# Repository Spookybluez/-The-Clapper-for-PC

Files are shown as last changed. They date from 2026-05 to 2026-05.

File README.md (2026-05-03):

# ESP32 PC Wake/Sleep Voice Bridge

An ESP32 prototype that listens through an I2S microphone and sends PC wake/sleep commands over the local network.

The current trigger is a calibrated clap detector. The network-control layer is ready for a future phrase recognizer such as "computer wake up" and "computer go to sleep."

## What It Does

- Reads a 6-pin I2S microphone from an ESP32.
- Uses a clap-style trigger to toggle desired PC state.
- Sends Wake-on-LAN packets to wake the PC.
- Sends an HTTP request to a small Windows listener to put the PC to sleep.
- Includes a dongle-style 3D-printable enclosure.

## Project Layout

| Path | Purpose |
| --- | --- |
| `PcWakeSleepVoiceBridge/` | Main ESP32 WiFi + Wake-on-LAN + sleep-listener firmware |
| `PcWakeSleepVoiceBridge/pc_power_listener.py` | Windows HTTP listener for dry-run and real sleep/shutdown actions |
| `PcWakeSleepVoiceBridge/arduino_secrets.example.h` | Template for local WiFi credentials |
| `ClapToggleWakeSensor/` | Earlier standalone I2S clap-toggle sketch |
| `UsbSerialWakeSleepBridge/` | Experimental USB-serial bridge variant |
| `enclosure/` | STL files and generator for the dongle-style case |

## Hardware

- ESP32 DevKit-style board
- 6-pin I2S microphone, such as INMP441-style modules
- USB power supply or USB cable
- PC with Wake-on-LAN-capable Ethernet adapter

I2S microphone wiring:

| Mic Pin | ESP32 Pin |
| --- | --- |
| `VDD` | `3V3` |
| `GND` | `GND` |
| `SCK` | `GPIO26` |
| `WS` | `GPIO25` |
| `SD` | `GPIO33` |
| `L/R` | `GND` |

## Main Firmware Setup

Copy the secrets template:

```powershell
copy .\PcWakeSleepVoiceBridge\arduino_secrets.example.h .\PcWakeSleepVoiceBridge\arduino_secrets.h
```

Edit `arduino_secrets.h` with your WiFi network:

```cpp
const char* WIFI_SSID = "YOUR_WIFI_NAME";
const char* WIFI_PASSWORD = "YOUR_WIFI_PASSWORD";
```

The PC target is configured in `PcWakeSleepVoiceBridge.ino`:

```cpp
const byte PC_MAC[6] = {0x34, 0x5A, 0x60, 0x10, 0x9F, 0x36};
const char* PC_SLEEP_URL = "http://192.168.1.191:8787/sleep";
```

Upload with Arduino IDE or Arduino CLI using an ESP32 Dev Module target.

## Windows Listener

Start in dry-run mode first:

```powershell
python .\PcWakeSleepVoiceBridge\pc_power_listener.py --dry-run
```

Dry-run endpoints report success without sleeping the PC.

When ready for the real sleep action:

```powershell
python .\PcWakeSleepVoiceBridge\pc_power_listener.py
```

Available endpoints:

- `GET /health`
- `POST /sleep`
- `POST /shutdown`

## Serial Test Commands

Open Serial Monitor at `115200` baud and send:

```text
WAKE_TEST
SLEEP_TEST
WAKE_IN_30
WAKE_SPAM_120
```

- `WAKE_TEST` sends one Wake-on-LAN packet.
- `SLEEP_TEST` calls the PC listener `/sleep` endpoint.
- `WAKE_IN_30` sends Wake-on-LAN after 30 seconds.
- `WAKE_SPAM_120` sends Wake-on-LAN repeatedly for 2 minutes.

## Wake-on-LAN Requirements

The PC must be configured to wake from the network adapter:

- BIOS/UEFI PCIe wake enabled
- Windows network adapter Power Management allows wake
- `Wake on Magic Packet` enabled in the adapter's advanced settings
- Ethernet connected to the active adapter

## Enclosure

Generated STL files:

- `enclosure/esp32_dongle_case_bottom.stl`
- `enclosure/esp32_dongle_case_lid.stl`

The case is a dongle-style shell with USB exiting the short end and mic grille slots on top.

## Safety Notes

- The firmware stores WiFi credentials in `arduino_secrets.h`, which is ignored by git.
- Use `--dry-run` before allowing the listener to sleep or shut down the PC.
- Wake-on-LAN can wake a sleeping/off PC only when BIOS, Windows, and the network adapter support it.

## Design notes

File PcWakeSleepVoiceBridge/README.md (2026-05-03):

# ESP32 PC Wake/Sleep Bridge

This version does not touch the motherboard `PWR_SW` header. The ESP32 sends signals to the PC over the network.

## What Works When

| PC state | Method | Requirement |
| --- | --- | --- |
| PC off/sleeping | Wake-on-LAN magic packet | Wake-on-LAN enabled in BIOS/UEFI and Windows/NIC settings |
| PC awake | HTTP request to listener | `pc_power_listener.py` running on the PC |

If the PC is fully off and Wake-on-LAN is disabled, the ESP32 cannot turn it on over USB/serial because the operating system is not running.

## ESP32 Setup

Create `arduino_secrets.h` from the example:

```powershell
copy .\arduino_secrets.example.h .\arduino_secrets.h
```

Then edit `arduino_secrets.h`:

```cpp
const char* WIFI_SSID = "YOUR_WIFI_NAME";
const char* WIFI_PASSWORD = "YOUR_WIFI_PASSWORD";
const char* PC_POWER_TOKEN = "MATCH_THE_TOKEN_IN_pc_listener_token.txt";
```

The PC target is currently configured in `PcWakeSleepVoiceBridge.ino`:

```cpp
const byte PC_MAC[6] = {0x34, 0x5A, 0x60, 0x10, 0x9F, 0x36};
const char* PC_SLEEP_URL = "http://192.168.1.191:8787/sleep";
```

The I2S mic wiring stays:

| Mic | ESP32 |
| --- | --- |
| VDD | 3V3 |
| GND | GND |
| SCK | GPIO26 |
| WS | GPIO25 |
| SD | GPIO33 |
| L/R | GND |

## Windows Listener

Create a local listener token file on the PC:

```powershell
[guid]::NewGuid().ToString('N') | Set-Content .\pc_listener_token.txt
```

Use the same token value for `PC_POWER_TOKEN` in `arduino_secrets.h`. The ESP32 sends it in the `X-Clapper-Token` header, and the listener rejects power commands without it.

Dry-run test:

```powershell
python .\pc_power_listener.py --dry-run --token (Get-Content .\pc_listener_token.txt)
```

Real sleep mode:

```powershell
python .\pc_power_listener.py --token (Get-Content .\pc_listener_token.txt)
```

Dry-run is strongly recommended first. Without `--dry-run`, `POST /sleep` will put the PC to sleep.

## ESP32 Serial Test Commands

Open Serial Monitor at `115200` baud and send one of:

```text
STATUS
THRESHOLD_1800
VERBOSE_ON
VERBOSE_OFF
CALIBRATE
WAKE_TEST
SLEEP_TEST
WAKE_IN_30
WAKE_SPAM_120
```

- `STATUS` prints Wi-Fi, mic, threshold, and action counters.
- `THRESHOLD_1800` changes the clap threshold. Replace `1800` with the target value.
- `VERBOSE_ON` / `VERBOSE_OFF` toggles periodic audio telemetry.
- `CALIBRATE` reruns the room-noise calibration.
- `WAKE_TEST` sends one Wake-on-LAN packet.
- `SLEEP_TEST` calls the PC listener `/sleep` endpoint.
- `WAKE_IN_30` sends Wake-on-LAN after 30 seconds.
- `WAKE_SPAM_120` sends Wake-on-LAN repeatedly for 2 minutes, useful for sleep/wake testing.

Set `VERBOSE_AUDIO_LOGS = true` in the sketch if you need raw mic tuning output again.

## ESP32 LAN Health Check

When the ESP32 is online, it exposes a read-only status endpoint:

```text
http://192.168.1.184:8080/health
```

The response includes Wi-Fi RSSI, uptime, mic readings, threshold, desired state, wake packet count, sleep request count, and the last sleep HTTP status. This endpoint does not trigger wake, sleep, or shutdown.

Remote tuning endpoints are available on the same port. These require the shared `X-Clapper-Token` header:

```powershell
$token = (Get-Content -Raw .\pc_listener_token.txt).Trim()
$headers = @{ "X-Clapper-Token" = $token }

Invoke-WebRequest -Method POST -UseBasicParsing -Headers $headers `
  -Uri "http://192.168.1.184:8080/config?threshold=1800&verbose=false"

Invoke-WebRequest -Method POST -UseBasicParsing -Headers $headers `
  -Uri "http://192.168.1.184:8080/calibrate"

Invoke-WebRequest -Method POST -UseBasicParsing -Headers $headers `
  -Uri "http://192.168.1.184:8080/wake_test"

Invoke-WebRequest -Method POST -UseBasicParsing -Headers $headers `
  -Uri "http://192.168.1.184:8080/reset_counters"
```

- `/config` can set `threshold` from `1` to `20000` and `verbose` to `true` or `false`.
- `/calibrate` reruns the mic room-noise calibration.
- `/wake_test` sends a Wake-on-LAN packet and increments `wakePacketsSent`.
- `/reset_counters` clears wake/sleep counters and the last sleep HTTP status.

There is intentionally no remote ESP endpoint for sleep. Sleep still only happens from the clap flow or the serial `SLEEP_TEST` command, which prevents accidental PC sleep while tuning over LAN.

## Voice Recognition

The included ESP32 sketch still uses the clap detector as a placeholder trigger. Exact phrase recognition like "computer wake up" and "computer go to sleep" should be added with an ESP32-S3/ESP-SR flow or a dedicated offline voice-recognition module. The network wake/sleep actions in this folder can remain the output layer.

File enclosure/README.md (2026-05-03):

# ESP32 Dongle-Style Enclosure

Generated STL files:

- `esp32_dongle_case_bottom.stl`
- `esp32_dongle_case_lid.stl`
- `esp32_dongle_case_lid_deep.stl`

Approximate outside dimensions:

- 78 mm long
- 42 mm wide
- 18 mm assembled height
- 28 mm assembled height with the deep lid

Design assumptions:

- Generic ESP32 DevKit-style board mounted lengthwise
- USB cable exits from the short end
- I2S mic sits near the opposite/top end behind five grille slots
- Bottom tray has rails and standoff pads for foam tape, hot glue, or small printed retention tweaks
- Lid uses a shallow internal lip rather than screws
- Deep lid adds 10 mm of extra wire space while using the same bottom tray

Print notes:

- Print both parts flat on the bed.
- PLA or PETG is fine.
- Use 0.2 mm layer height.
- No supports should be needed.

If the USB port, ESP32 board, or mic module do not line up, edit `generate_dongle_case_stl.py` and rerun it.

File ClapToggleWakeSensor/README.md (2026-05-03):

# ESP32 I2S Clap Toggle Sensor

Open `ClapToggleWakeSensor.ino` in Arduino IDE.

## Wiring

| Module | ESP32 |
| --- | --- |
| Mic VDD | 3V3 |
| Mic GND | GND |
| Mic SCK | GPIO26 |
| Mic WS | GPIO25 |
| Mic SD | GPIO33 |
| Mic L/R | GND |
| Built-in LED | GPIO2 |
| PC power trigger output | GPIO14 |

Tie `L/R` to `GND` for the left audio channel. If readings stay near zero after wiring, move `L/R` to `3V3` and change the sketch channel from `I2S_CHANNEL_FMT_ONLY_LEFT` to `I2S_CHANNEL_FMT_ONLY_RIGHT`.

## Arduino IDE Settings

- Board: your ESP32 dev board, often `ESP32 Dev Module`
- Serial Monitor: `115200 baud`

## Tuning

The sketch prints `peak`, `threshold`, `noise`, and `system` about four times per second.

- If normal room noise toggles the system, raise `CLAP_THRESHOLD`.
- If claps do not toggle it, lower `CLAP_THRESHOLD`.
- The sketch calibrates room noise for about two seconds at startup, so stay quiet after reset.

## Speaker Note

Do not connect the bare speaker directly to an ESP32 GPIO. Use a small audio amplifier module, then we can add an audible ON/OFF chirp safely.

## PC Power Button Wiring

Use an optocoupler or a small relay module to imitate the PC case power button.

Preferred optocoupler wiring:

| ESP32 side | Optocoupler input |
| --- | --- |
| GPIO14 | 220 ohm resistor -> optocoupler LED anode |
| GND | optocoupler LED cathode |

| PC side | Optocoupler output |
| --- | --- |
| Motherboard `PWR_SW` pin 1 | optocoupler transistor collector |
| Motherboard `PWR_SW` pin 2 | optocoupler transistor emitter |

If it does not trigger, swap the collector/emitter wires on the motherboard side. Leave the existing case power-button cable connected if you can fit both, or use a splitter.

Do not connect the ESP32 GPIO directly to the motherboard header. Do not switch AC wall power. This sketch sends a short 250 ms button press only.

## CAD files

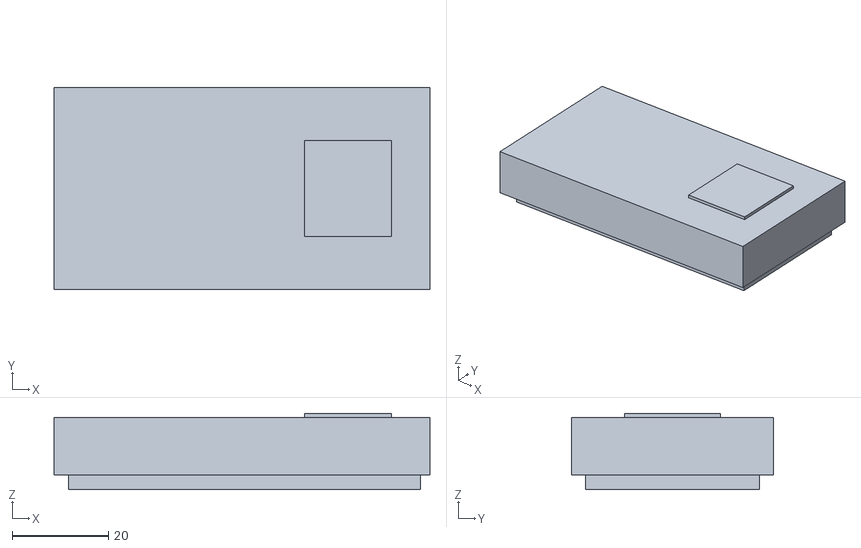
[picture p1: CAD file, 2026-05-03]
enclosure/esp32_dongle_case_lid_deep.stl
78.0 x 42.0 x 15.8

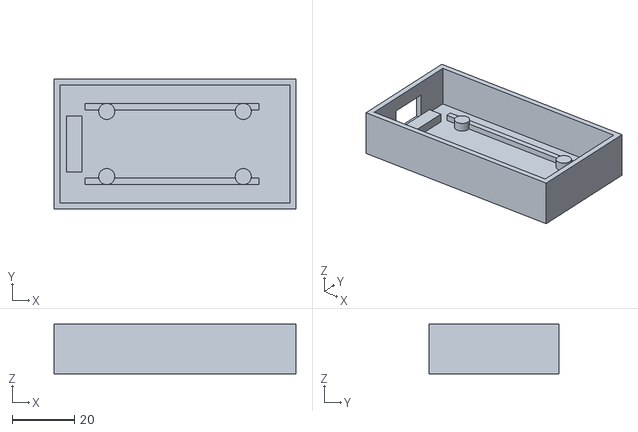
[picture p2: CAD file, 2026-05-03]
enclosure/esp32_dongle_case_bottom.stl
78.0 x 42.0 x 16.0

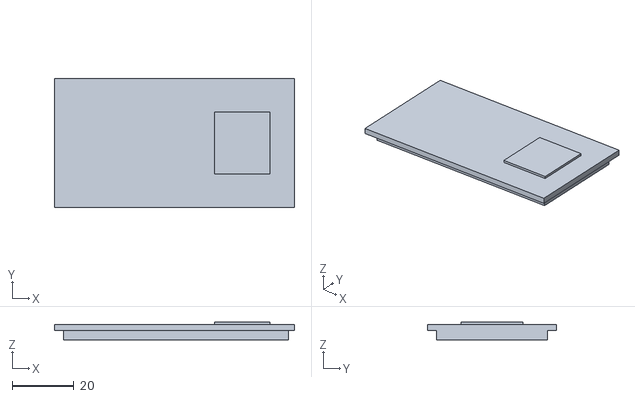
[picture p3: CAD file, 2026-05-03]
enclosure/esp32_dongle_case_lid.stl
78.0 x 42.0 x 5.80

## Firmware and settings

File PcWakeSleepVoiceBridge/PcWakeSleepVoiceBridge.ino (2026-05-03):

/*
  ESP32 PC wake/sleep signal bridge

  This sketch keeps the I2S mic clap detector from the prototype, but replaces
  the physical PC power-button output with network signals:

    - "Wake" action: send Wake-on-LAN magic packet to the PC MAC address.
    - "Sleep" action: call a tiny HTTP listener running on the PC.

  Later, replace the clap detector with real speech recognition or an external
  voice-recognition module. The network control pieces can stay the same.
*/

#include <Arduino.h>
#include <WiFi.h>
#include <WiFiUdp.h>
#include <HTTPClient.h>
#include <WebServer.h>
#include <driver/i2s.h>

#include "arduino_secrets.h"

const byte PC_MAC[6] = {0x34, 0x5A, 0x60, 0x10, 0x9F, 0x36};
const char* PC_SLEEP_URL = "http://192.168.1.191:8787/sleep";
const int STATUS_SERVER_PORT = 8080;

const i2s_port_t I2S_PORT = I2S_NUM_0;
WebServer statusServer(STATUS_SERVER_PORT);
const char* STATUS_SERVER_HEADERS[] = {"X-Clapper-Token"};

const int I2S_SCK_PIN = 26;
const int I2S_WS_PIN = 25;
const int I2S_SD_PIN = 33;
const int STATUS_LED_PIN = 2;

const int SAMPLE_RATE = 16000;
const int BUFFER_SAMPLES = 256;

const unsigned long CALIBRATION_MS = 1800;
const unsigned long CLAP_LOCKOUT_MS = 1200;
const unsigned long PRINT_INTERVAL_MS = 2000;

const int CLAP_THRESHOLD = 1800;
const bool DEFAULT_VERBOSE_AUDIO_LOGS = false;

struct AudioStats {
  int peak;
  int average;
};

int32_t samples[BUFFER_SAMPLES];
int clapThreshold = CLAP_THRESHOLD;
int noiseFloor = 0;
bool verboseAudioLogs = DEFAULT_VERBOSE_AUDIO_LOGS;
bool pcWantedAwake = false;
unsigned long lastClapAt = 0;
unsigned long lastPrintAt = 0;
unsigned long scheduledWakeAt = 0;
unsigned long wakeSpamUntil = 0;
unsigned long nextWakeSpamAt = 0;
unsigned long wakePacketsSent = 0;
unsigned long sleepRequestsSent = 0;
int lastAverage = 0;
int lastPeak = 0;
int lastSleepHttpStatus = 0;
String lastAction = "boot";

void connectWiFi();
void setupStatusServer();
void handleStatusServer();
bool isAuthorized();
String healthJson();
void sendJson(int status, const String& body);
void handleConfig();
void handleCalibrate();
void handleWakeTest();
void handleResetCounters();
void setupI2SMic();
AudioStats readI2SStats();
void calibrateNoiseFloor();
void sendWakeOnLan();
void sendSleepRequest();
void handleSerialCommand();
void printStatus(const AudioStats& audio);

void setup() {
  Serial.begin(115200);
  delay(500);

  pinMode(STATUS_LED_PIN, OUTPUT);
  digitalWrite(STATUS_LED_PIN, LOW);

  Serial.println();
  Serial.println("ESP32 PC wake/sleep bridge starting.");
  connectWiFi();
  setupStatusServer();
  setupI2SMic();
  calibrateNoiseFloor();

  Serial.println("READY: clap toggles WAKE/SLEEP. Commands: STATUS, WAKE_TEST, SLEEP_TEST, WAKE_IN_30, WAKE_SPAM_120.");
}

void loop() {
  handleStatusServer();
  handleSerialCommand();

  if (scheduledWakeAt != 0 && (long)(millis() - scheduledWakeAt) >= 0) {
    scheduledWakeAt = 0;
    Serial.println("Scheduled wake firing now.");
    sendWakeOnLan();
  }

  if (wakeSpamUntil != 0 && (long)(millis() - wakeSpamUntil) < 0 &&
      (long)(millis() - nextWakeSpamAt) >= 0) {
    nextWakeSpamAt = millis() + 10000UL;
    Serial.println("Repeated wake firing now.");
    sendWakeOnLan();
  } else if (wakeSpamUntil != 0 && (long)(millis() - wakeSpamUntil) >= 0) {
    wakeSpamUntil = 0;
    nextWakeSpamAt = 0;
    Serial.println("Repeated wake window ended.");
  }

  AudioStats audio = readI2SStats();
  lastAverage = audio.average;
  lastPeak = audio.peak;
  unsigned long now = millis();
  bool clapDetected = audio.average >= clapThreshold;

  if (clapDetected && now - lastClapAt >= CLAP_LOCKOUT_MS) {
    lastClapAt = now;
    pcWantedAwake = !pcWantedAwake;
    digitalWrite(STATUS_LED_PIN, pcWantedAwake ? HIGH : LOW);

    if (pcWantedAwake) {
      lastAction = "wake";
      Serial.print("VOICE_TRIGGER -> WAKE avg=");
      Serial.print(audio.average);
      Serial.print(" peak=");
      Serial.println(audio.peak);
      sendWakeOnLan();
    } else {
      lastAction = "sleep";
      Serial.print("VOICE_TRIGGER -> SLEEP avg=");
      Serial.print(audio.average);
      Serial.print(" peak=");
      Serial.println(audio.peak);
      sendSleepRequest();
    }
  }

  if (verboseAudioLogs && now - lastPrintAt >= PRINT_INTERVAL_MS) {
    lastPrintAt = now;
    printStatus(audio);
  }
}

void handleSerialCommand() {
  if (!Serial.available()) {
    return;
  }

  String command = Serial.readStringUntil('\n');
  command.trim();
  command.toUpperCase();

  if (command == "WAKE_TEST") {
    Serial.println("Serial command -> WAKE_TEST");
    lastAction = "serial_wake_test";
    sendWakeOnLan();
  } else if (command.startsWith("WAKE_IN_")) {
    int seconds = command.substring(8).toInt();
    if (seconds <= 0) {
      seconds = 30;
    }
    scheduledWakeAt = millis() + (unsigned long)seconds * 1000UL;
    Serial.print("Serial command -> scheduled WAKE in seconds: ");
    Serial.println(seconds);
  } else if (command.startsWith("WAKE_SPAM_")) {
    int seconds = command.substring(10).toInt();
    if (seconds <= 0) {
      seconds = 120;
    }
    wakeSpamUntil = millis() + (unsigned long)seconds * 1000UL;
    nextWakeSpamAt = millis() + 5000UL;
    Serial.print("Serial command -> repeated WAKE window seconds: ");
    Serial.println(seconds);
  } else if (command == "SLEEP_TEST") {
    Serial.println("Serial command -> SLEEP_TEST");
    lastAction = "serial_sleep_test";
    sendSleepRequest();
  } else if (command == "STATUS") {
    Serial.print("STATUS ip=");
    Serial.print(WiFi.localIP());
    Serial.print(" rssi=");
    Serial.print(WiFi.RSSI());
    Serial.print(" avg=");
    Serial.print(lastAverage);
    Serial.print(" peak=");
    Serial.print(lastPeak);
    Serial.print(" threshold=");
    Serial.print(clapThreshold);
    Serial.print(" verbose=");
    Serial.print(verboseAudioLogs ? "ON" : "OFF");
    Serial.print(" desired=");
    Serial.print(pcWantedAwake ? "AWAKE" : "SLEEP");
    Serial.print(" wakePackets=");
    Serial.print(wakePacketsSent);
    Serial.print(" sleepRequests=");
    Serial.print(sleepRequestsSent);
    Serial.print(" lastSleepHttp=");
    Serial.print(lastSleepHttpStatus);
    Serial.print(" lastAction=");
    Serial.println(lastAction);
  } else if (command.startsWith("THRESHOLD_")) {
    int threshold = command.substring(10).toInt();
    if (threshold >= 1 && threshold <= 20000) {
      clapThreshold = threshold;
      Serial.print("Serial command -> threshold set to ");
      Serial.println(clapThreshold);
    } else {
      Serial.println("Threshold must be between 1 and 20000.");
    }
  } else if (command == "VERBOSE_ON") {
    verboseAudioLogs = true;
    Serial.println("Serial command -> verbose audio logs ON");
  } else if (command == "VERBOSE_OFF") {
    verboseAudioLogs = false;
    Serial.println("Serial command -> verbose audio logs OFF");
  } else if (command == "CALIBRATE") {
    Serial.println("Serial command -> CALIBRATE");
    calibrateNoiseFloor();
  } else if (command.length() > 0) {
    Serial.print("Unknown serial command: ");
    Serial.println(command);
  }
}

void setupStatusServer() {
  if (WiFi.status() != WL_CONNECTED) {
    Serial.println("Status server skipped: WiFi is not connected.");
    return;
  }

  statusServer.collectHeaders(STATUS_SERVER_HEADERS, 1);
  statusServer.on("/health", HTTP_GET, []() {
    sendJson(200, healthJson());
  });
  statusServer.on("/status", HTTP_GET, []() {
    sendJson(200, healthJson());
  });
  statusServer.on("/config", HTTP_POST, handleConfig);
  statusServer.on("/calibrate", HTTP_POST, handleCalibrate);
  statusServer.on("/wake_test", HTTP_POST, handleWakeTest);
  statusServer.on("/reset_counters", HTTP_POST, handleResetCounters);

  statusServer.onNotFound([]() {
    statusServer.send(404, "application/json", "{\"ok\":false,\"error\":\"not found\"}");
  });

  statusServer.begin();
  Serial.print("ESP status server listening on http://");
  Serial.print(WiFi.localIP());
  Serial.print(":");
  Serial.println(STATUS_SERVER_PORT);
}

bool isAuthorized() {
  if (String(PC_POWER_TOKEN).length() == 0) {
    return true;
  }
  if (statusServer.header("X-Clapper-Token") == PC_POWER_TOKEN) {
    return true;
  }
  return statusServer.hasArg("token") && statusServer.arg("token") == PC_POWER_TOKEN;
}

String healthJson() {
  String body = "{";
  body += "\"ok\":true";
  body += ",\"ip\":\"" + WiFi.localIP().toString() + "\"";
  body += ",\"rssi\":" + String(WiFi.RSSI());
  body += ",\"uptimeMs\":" + String(millis());
  body += ",\"noiseFloor\":" + String(noiseFloor);
  body += ",\"threshold\":" + String(clapThreshold);
  body += ",\"verboseAudioLogs\":" + String(verboseAudioLogs ? "true" : "false");
  body += ",\"lastAverage\":" + String(lastAverage);
  body += ",\"lastPeak\":" + String(lastPeak);
  body += ",\"desired\":\"" + String(pcWantedAwake ? "AWAKE" : "SLEEP") + "\"";
  body += ",\"wakePacketsSent\":" + String(wakePacketsSent);
  body += ",\"sleepRequestsSent\":" + String(sleepRequestsSent);
  body += ",\"lastSleepHttpStatus\":" + String(lastSleepHttpStatus);
  body += ",\"lastAction\":\"" + lastAction + "\"";
  body += "}";
  return body;
}

void sendJson(int status, const String& body) {
  statusServer.send(status, "application/json", body);
}

void handleConfig() {
  if (!isAuthorized()) {
    sendJson(401, "{\"ok\":false,\"error\":\"unauthorized\"}");
    return;
  }

  if (statusServer.hasArg("threshold")) {
    int threshold = statusServer.arg("threshold").toInt();
    if (threshold < 1 || threshold > 20000) {
      sendJson(400, "{\"ok\":false,\"error\":\"threshold must be 1..20000\"}");
      return;
    }
    clapThreshold = threshold;
  }

  if (statusServer.hasArg("verbose")) {
    String value = statusServer.arg("verbose");
    value.toLowerCase();
    verboseAudioLogs = value == "1" || value == "true" || value == "on" || value == "yes";
  }

  lastAction = "remote_config";
  sendJson(200, healthJson());
}

void handleCalibrate() {
  if (!isAuthorized()) {
    sendJson(401, "{\"ok\":false,\"error\":\"unauthorized\"}");
    return;
  }

  lastAction = "remote_calibrate";
  calibrateNoiseFloor();
  sendJson(200, healthJson());
}

void handleWakeTest() {
  if (!isAuthorized()) {
    sendJson(401, "{\"ok\":false,\"error\":\"unauthorized\"}");
    return;
  }

  lastAction = "remote_wake_test";
  sendWakeOnLan();
  sendJson(200, healthJson());
}

void handleResetCounters() {
  if (!isAuthorized()) {
    sendJson(401, "{\"ok\":false,\"error\":\"unauthorized\"}");
    return;
  }

  wakePacketsSent = 0;
  sleepRequestsSent = 0;
  lastSleepHttpStatus = 0;
  lastAction = "remote_reset_counters";
  sendJson(200, healthJson());
}

void handleStatusServer() {
  if (WiFi.status() == WL_CONNECTED) {
    statusServer.handleClient();
  }
}

void connectWiFi() {
  WiFi.mode(WIFI_STA);
  WiFi.begin(WIFI_SSID, WIFI_PASSWORD);

  Serial.print("Connecting to WiFi");
  unsigned long startedAt = millis();
  while (WiFi.status() != WL_CONNECTED && millis() - startedAt < 20000UL) {
    delay(500);
    Serial.print(".");
  }

  Serial.println();
  if (WiFi.status() != WL_CONNECTED) {
    Serial.println("WiFi connection failed. Commands will retry when needed.");
    return;
  }

  Serial.print("WiFi connected. ESP32 IP: ");
  Serial.println(WiFi.localIP());
}

void setupI2SMic() {
  i2s_config_t i2sConfig = {
    .mode = (i2s_mode_t)(I2S_MODE_MASTER | I2S_MODE_RX),
    .sample_rate = SAMPLE_RATE,
    .bits_per_sample = I2S_BITS_PER_SAMPLE_32BIT,
    .channel_format = I2S_CHANNEL_FMT_ONLY_RIGHT,
    .communication_format = I2S_COMM_FORMAT_STAND_I2S,
    .intr_alloc_flags = ESP_INTR_FLAG_LEVEL1,
    .dma_buf_count = 4,
    .dma_buf_len = BUFFER_SAMPLES,
    .use_apll = false,
    .tx_desc_auto_clear = false,
    .fixed_mclk = 0
  };

  i2s_pin_config_t pinConfig = {
    .bck_io_num = I2S_SCK_PIN,
    .ws_io_num = I2S_WS_PIN,
    .data_out_num = I2S_PIN_NO_CHANGE,
    .data_in_num = I2S_SD_PIN
  };

  esp_err_t err = i2s_driver_install(I2S_PORT, &i2sConfig, 0, NULL);
  if (err != ESP_OK) {
    Serial.print("I2S driver install failed: ");
    Serial.println(err);
    while (true) delay(1000);
  }

  err = i2s_set_pin(I2S_PORT, &pinConfig);
  if (err != ESP_OK) {
    Serial.print("I2S pin setup failed: ");
    Serial.println(err);
    while (true) delay(1000);
  }

  i2s_zero_dma_buffer(I2S_PORT);
}

void calibrateNoiseFloor() {
  Serial.println("Calibrating room noise. Stay quiet for about 2 seconds...");

  unsigned long startedAt = millis();
  long totalAverage = 0;
  int windows = 0;

  while (millis() - startedAt < CALIBRATION_MS) {
    AudioStats audio = readI2SStats();
    totalAverage += audio.average;
    windows++;
  }

  noiseFloor = windows > 0 ? totalAverage / windows : 0;

  Serial.print("Noise floor=");
  Serial.println(noiseFloor);
  Serial.print("Trigger threshold=");
  Serial.println(clapThreshold);
}

AudioStats readI2SStats() {
  size_t bytesRead = 0;
  esp_err_t err = i2s_read(I2S_PORT, samples, sizeof(samples), &bytesRead, portMAX_DELAY);
  if (err != ESP_OK || bytesRead == 0) {
    return {0, 0};
  }

  int sampleCount = bytesRead / sizeof(samples[0]);
  int peak = 0;
  int64_t totalMagnitude = 0;

  for (int i = 0; i < sampleCount; i++) {
    int32_t scaled = samples[i] >> 14;
    int magnitude = abs((int)scaled);
    totalMagnitude += magnitude;
    if (magnitude > peak) {
      peak = magnitude;
    }
  }

  int average = sampleCount > 0 ? totalMagnitude / sampleCount : 0;
  return {peak, average};
}

void sendWakeOnLan() {
  if (WiFi.status() != WL_CONNECTED) {
    connectWiFi();
  }

  if (WiFi.status() != WL_CONNECTED) {
    Serial.println("Wake-on-LAN skipped: WiFi is not connected.");
    return;
  }

  byte packet[102];
  memset(packet, 0xFF, 6);

  for (int i = 1; i <= 16; i++) {
    memcpy(&packet[i * 6], PC_MAC, 6);
  }

  WiFiUDP udp;
  udp.beginPacket(IPAddress(255, 255, 255, 255), 9);
  udp.write(packet, sizeof(packet));
  udp.endPacket();
  udp.stop();

  wakePacketsSent++;
  Serial.println("Wake-on-LAN packet sent.");
}

void sendSleepRequest() {
  if (WiFi.status() != WL_CONNECTED) {
    connectWiFi();
  }

  if (WiFi.status() != WL_CONNECTED) {
    Serial.println("Sleep request skipped: WiFi is not connected.");
    return;
  }

  Serial.print("WiFi status: ");
  Serial.println(WiFi.status());
  Serial.print("ESP32 IP: ");
  Serial.println(WiFi.localIP());
  Serial.print("POST ");
  Serial.println(PC_SLEEP_URL);

  HTTPClient http;
  http.begin(PC_SLEEP_URL);
  http.addHeader("X-Clapper-Token", PC_POWER_TOKEN);
  int status = http.POST("");
  lastSleepHttpStatus = status;
  sleepRequestsSent++;
  Serial.print("Sleep request HTTP status: ");
  Serial.println(status);
  if (status < 0) {
    Serial.print("HTTP error: ");
    Serial.println(http.errorToString(status));
  }
  http.end();
}

void printStatus(const AudioStats& audio) {
  Serial.print("avg=");
  Serial.print(audio.average);
  Serial.print(" peak=");
  Serial.print(audio.peak);
  Serial.print(" threshold=");
  Serial.print(clapThreshold);
  Serial.print(" desired=");
  Serial.println(pcWantedAwake ? "AWAKE" : "SLEEP");
}

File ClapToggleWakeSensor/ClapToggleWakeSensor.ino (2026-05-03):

/*
  ESP32 I2S mic clap toggle sensor

  Wiring for a 6-pin I2S mic such as INMP441:
    Mic VDD       -> ESP32 3V3
    Mic GND       -> ESP32 GND
    Mic SCK/BCLK  -> ESP32 GPIO26
    Mic WS/LRCL   -> ESP32 GPIO25
    Mic SD/DOUT   -> ESP32 GPIO33
    Mic L/R       -> ESP32 GND

  Clap once to toggle system ON/OFF. The built-in LED on GPIO2 shows state.
  GPIO14 pulses an optocoupler/relay that is wired across the PC motherboard
  PWR_SW header pins, imitating a momentary front-panel power button press.
*/

#include <Arduino.h>
#include <driver/i2s.h>

const i2s_port_t I2S_PORT = I2S_NUM_0;

const int I2S_SCK_PIN = 26;
const int I2S_WS_PIN = 25;
const int I2S_SD_PIN = 33;
const int STATUS_LED_PIN = 2;
const int PC_POWER_TRIGGER_PIN = 14;

const int SAMPLE_RATE = 16000;
const int BUFFER_SAMPLES = 256;

const unsigned long CALIBRATION_MS = 1800;
const unsigned long CLAP_LOCKOUT_MS = 900;
const unsigned long PRINT_INTERVAL_MS = 250;
const unsigned long PC_POWER_PULSE_MS = 250;

// These values are scaled average-energy units. If normal speech triggers it,
// raise CLAP_THRESHOLD. If claps do not trigger it, lower CLAP_THRESHOLD.
const int CLAP_THRESHOLD = 1800;

int clapThreshold = CLAP_THRESHOLD;
int noiseFloor = 0;
bool systemOn = false;
unsigned long lastClapAt = 0;
unsigned long lastPrintAt = 0;

struct AudioStats {
  int peak;
  int average;
};

int32_t samples[BUFFER_SAMPLES];

void setupI2SMic();
AudioStats readI2SStats();
void calibrateNoiseFloor();
void pulsePcPowerButton();

void setup() {
  Serial.begin(115200);
  delay(500);

  pinMode(STATUS_LED_PIN, OUTPUT);
  pinMode(PC_POWER_TRIGGER_PIN, OUTPUT);
  digitalWrite(STATUS_LED_PIN, LOW);
  digitalWrite(PC_POWER_TRIGGER_PIN, LOW);

  Serial.println();
  Serial.println("ESP32 I2S clap toggle starting... channel=RIGHT");
  setupI2SMic();
  calibrateNoiseFloor();

  Serial.println("Clap toggle ready.");
  Serial.println("Open Serial Monitor at 115200 baud. Clap once to toggle ON/OFF.");
}

void loop() {
  AudioStats audio = readI2SStats();
  unsigned long now = millis();
  bool clapDetected = audio.average >= clapThreshold;

  if (clapDetected && now - lastClapAt >= CLAP_LOCKOUT_MS) {
    lastClapAt = now;
    systemOn = !systemOn;
    digitalWrite(STATUS_LED_PIN, systemOn ? HIGH : LOW);
    pulsePcPowerButton();

    Serial.print("CLAP avg=");
    Serial.print(audio.average);
    Serial.print(" peak=");
    Serial.print(audio.peak);
    Serial.print(" -> system ");
    Serial.println(systemOn ? "ON" : "OFF");
  }

  if (now - lastPrintAt >= PRINT_INTERVAL_MS) {
    lastPrintAt = now;
    Serial.print("avg=");
    Serial.print(audio.average);
    Serial.print(" peak=");
    Serial.print(audio.peak);
    Serial.print(" threshold=");
    Serial.print(clapThreshold);
    Serial.print(" noise=");
    Serial.print(noiseFloor);
    Serial.print(" system=");
    Serial.println(systemOn ? "ON" : "OFF");
  }
}

void pulsePcPowerButton() {
  digitalWrite(PC_POWER_TRIGGER_PIN, HIGH);
  delay(PC_POWER_PULSE_MS);
  digitalWrite(PC_POWER_TRIGGER_PIN, LOW);
}

void setupI2SMic() {
  i2s_config_t i2sConfig = {
    .mode = (i2s_mode_t)(I2S_MODE_MASTER | I2S_MODE_RX),
    .sample_rate = SAMPLE_RATE,
    .bits_per_sample = I2S_BITS_PER_SAMPLE_32BIT,
    .channel_format = I2S_CHANNEL_FMT_ONLY_RIGHT,
    .communication_format = I2S_COMM_FORMAT_STAND_I2S,
    .intr_alloc_flags = ESP_INTR_FLAG_LEVEL1,
    .dma_buf_count = 4,
    .dma_buf_len = BUFFER_SAMPLES,
    .use_apll = false,
    .tx_desc_auto_clear = false,
    .fixed_mclk = 0
  };

  i2s_pin_config_t pinConfig = {
    .bck_io_num = I2S_SCK_PIN,
    .ws_io_num = I2S_WS_PIN,
    .data_out_num = I2S_PIN_NO_CHANGE,
    .data_in_num = I2S_SD_PIN
  };

  esp_err_t err = i2s_driver_install(I2S_PORT, &i2sConfig, 0, NULL);
  if (err != ESP_OK) {
    Serial.print("I2S driver install failed: ");
    Serial.println(err);
    while (true) {
      delay(1000);
    }
  }

  err = i2s_set_pin(I2S_PORT, &pinConfig);
  if (err != ESP_OK) {
    Serial.print("I2S pin setup failed: ");
    Serial.println(err);
    while (true) {
      delay(1000);
    }
  }

  i2s_zero_dma_buffer(I2S_PORT);
}

void calibrateNoiseFloor() {
  Serial.println("Calibrating room noise. Stay quiet for about 2 seconds...");

  unsigned long startedAt = millis();
  long totalPeak = 0;
  int windows = 0;
  int maxPeak = 0;

  while (millis() - startedAt < CALIBRATION_MS) {
    AudioStats audio = readI2SStats();
    totalPeak += audio.average;
    windows++;
    if (audio.average > maxPeak) {
      maxPeak = audio.average;
    }
  }

  noiseFloor = windows > 0 ? totalPeak / windows : 0;
  clapThreshold = CLAP_THRESHOLD;

  Serial.print("Noise floor=");
  Serial.println(noiseFloor);
  Serial.print("Max startup noise=");
  Serial.println(maxPeak);
  Serial.print("Clap threshold=");
  Serial.println(clapThreshold);
}

AudioStats readI2SStats() {
  size_t bytesRead = 0;
  esp_err_t err = i2s_read(I2S_PORT, samples, sizeof(samples), &bytesRead, portMAX_DELAY);
  if (err != ESP_OK || bytesRead == 0) {
    return {0, 0};
  }

  int sampleCount = bytesRead / sizeof(samples[0]);
  int peak = 0;
  int64_t totalMagnitude = 0;

  for (int i = 0; i < sampleCount; i++) {
    // INMP441-style mics usually provide 24-bit audio left-aligned in 32 bits.
    int32_t scaled = samples[i] >> 14;
    int magnitude = abs((int)scaled);
    totalMagnitude += magnitude;
    if (magnitude > peak) {
      peak = magnitude;
    }
  }

  int average = sampleCount > 0 ? totalMagnitude / sampleCount : 0;
  return {peak, average};
}

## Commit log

2026-05-03 Initial ESP32 PC wake sleep bridge
    [esp32_dongle_case_bottom.stl, esp32_dongle_case_lid.stl]
2026-05-03 Add ESP health endpoint and deep enclosure lid
    [esp32_dongle_case_lid_deep.stl]
